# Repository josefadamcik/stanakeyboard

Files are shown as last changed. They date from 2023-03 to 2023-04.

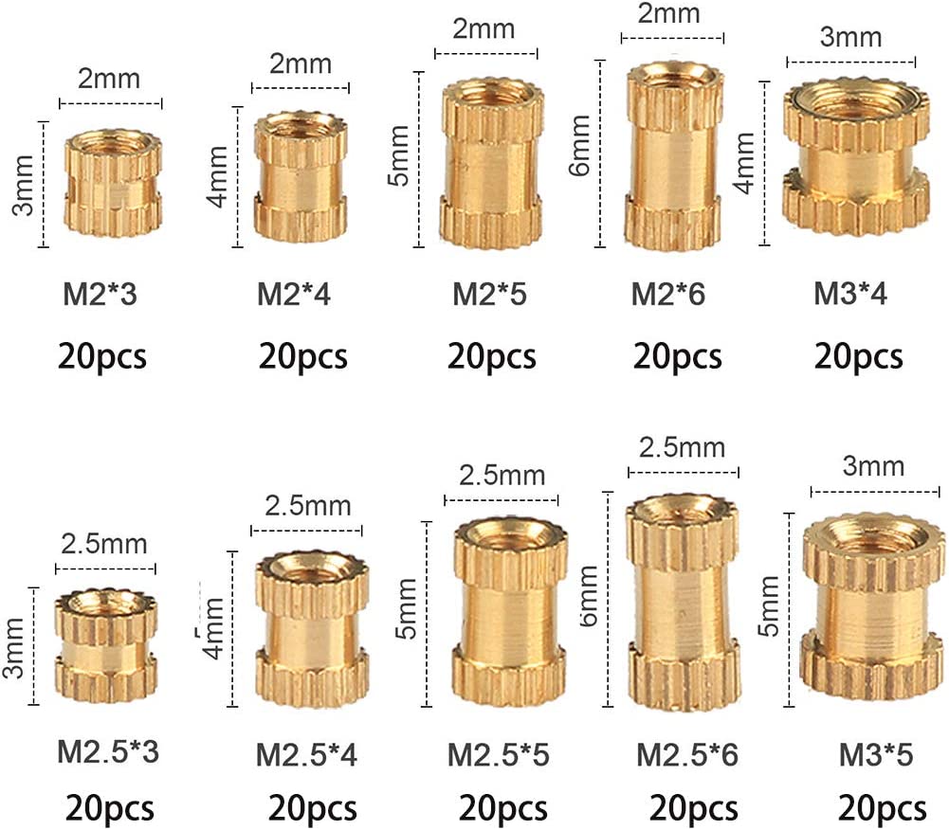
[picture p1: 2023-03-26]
doc/heat_inserts.jpg

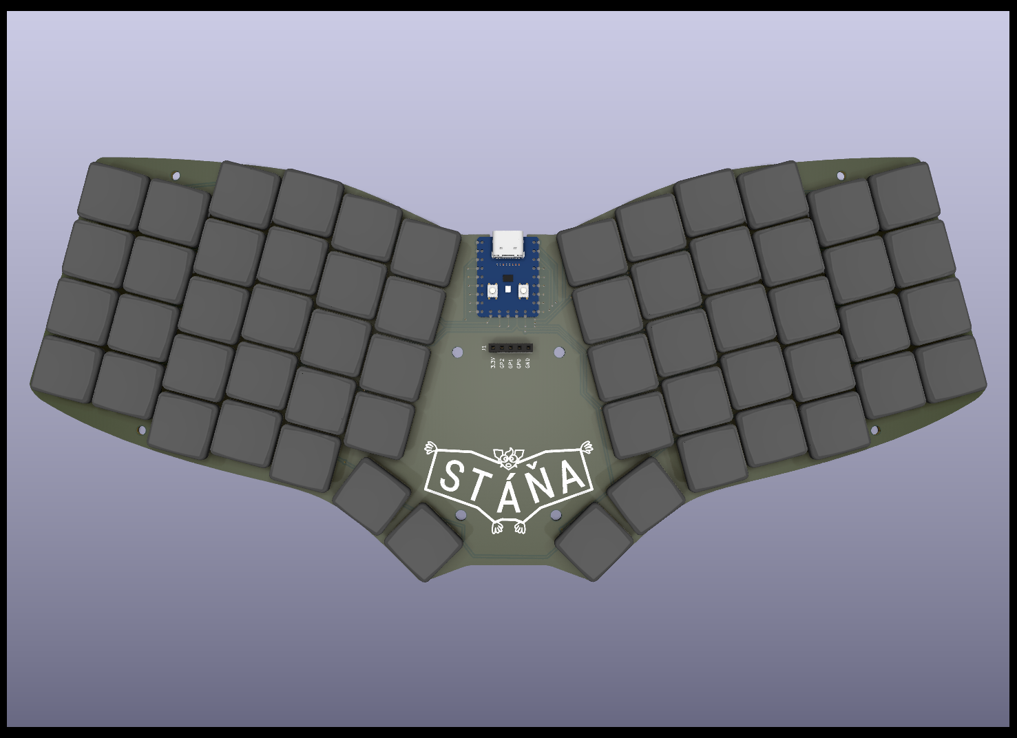
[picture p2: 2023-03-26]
doc/Stana_v0_1_render1.png

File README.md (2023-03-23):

# sofleunsplit

WIP DIY keyboard design.

* Sofle V2 layout
* But Kailh Chock with 18x17 spacing, socketed
* one board, one micro
* WaveShare RP2040
* no PCB plates -> case is going to be 3d printed/lasercut or something
* no RGB support

## Requirements

* Uses symbols/footprints from https://github.com/zzeneg/zzkeeb

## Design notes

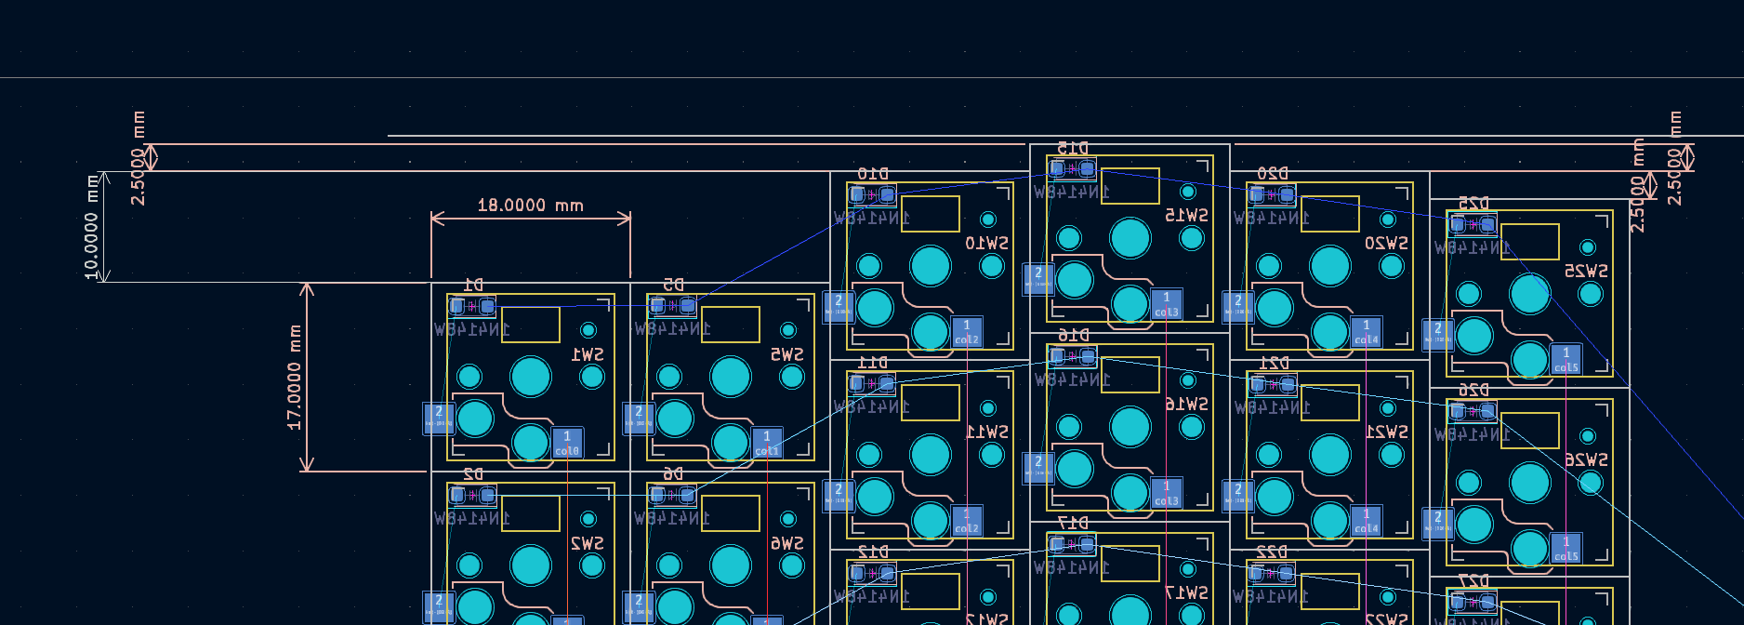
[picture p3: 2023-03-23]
doc/stagger.png

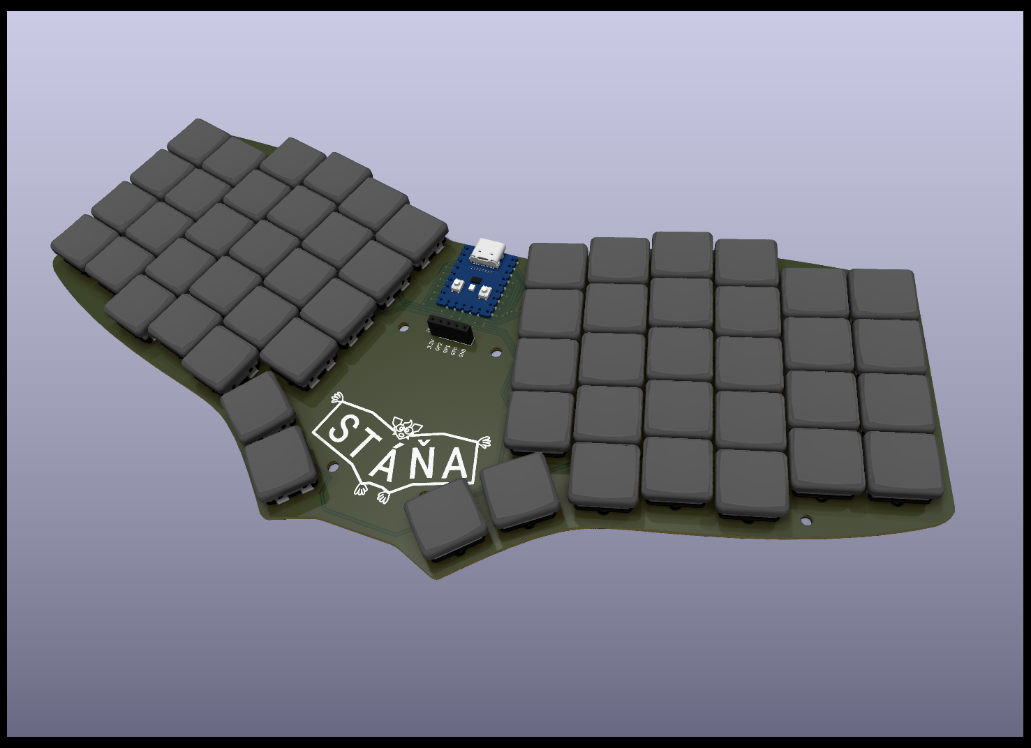
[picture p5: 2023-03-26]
doc/Stana_v0_1_render3.png

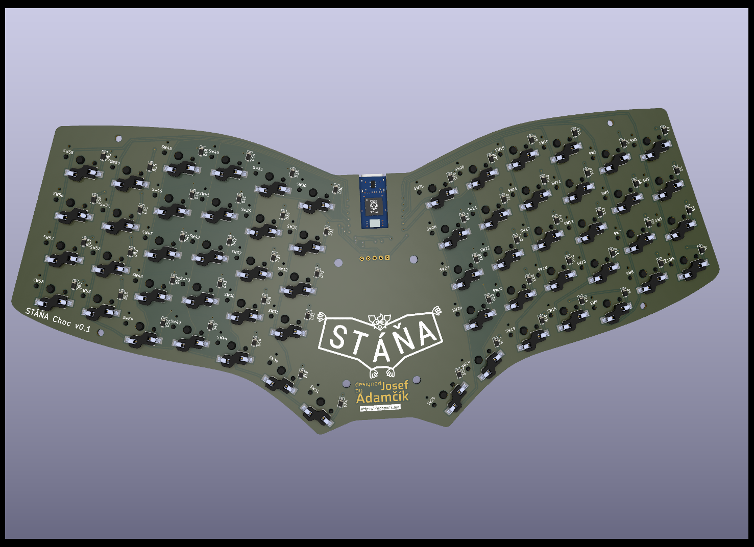
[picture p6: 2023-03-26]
doc/Stana_v0_1_render2.png

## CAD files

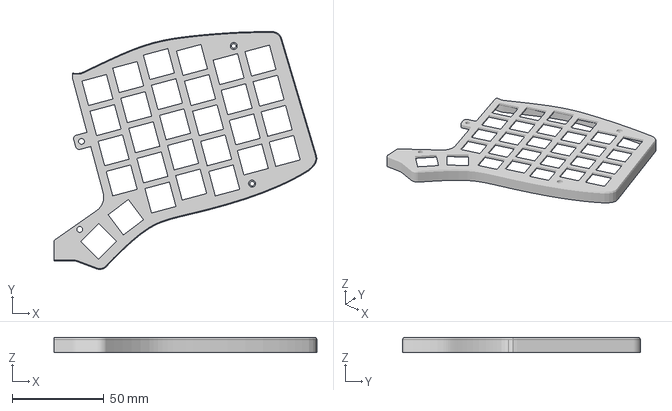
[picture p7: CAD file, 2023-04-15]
case/TopRightMirrorv4.3mf
143.4 x 129.7 x 8.00 mm

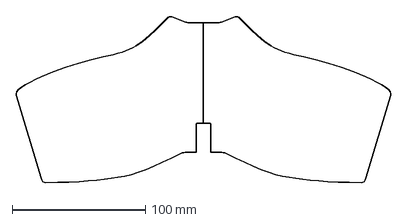
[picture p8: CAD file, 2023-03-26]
outline_design2.dxf
281.5 x 124.8 mm

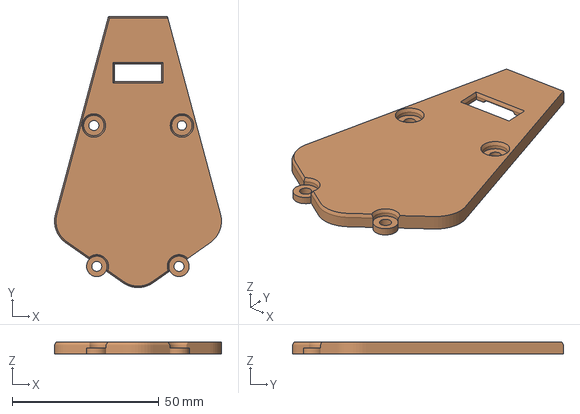
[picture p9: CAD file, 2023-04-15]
case/MiddleCover.3mf
56.9 x 92.4 x 4.00 mm

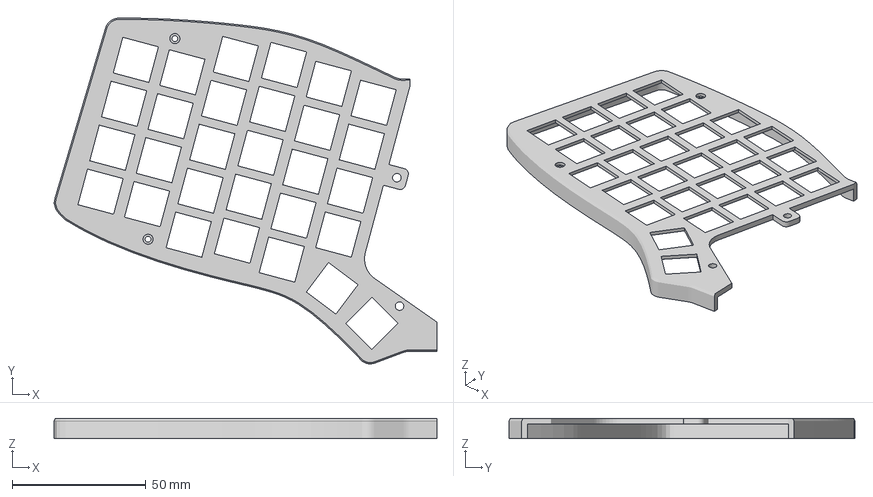
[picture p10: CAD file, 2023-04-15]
case/TopLeftv2.3mf
143.2 x 129.3 x 7.60 mm

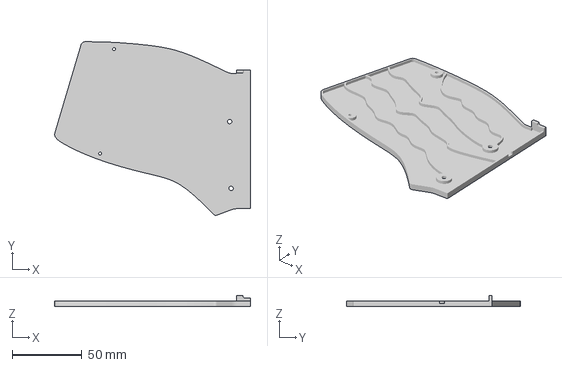
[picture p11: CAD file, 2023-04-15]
case/BottomLeft.3mf
140.8 x 124.7 x 7.80 mm

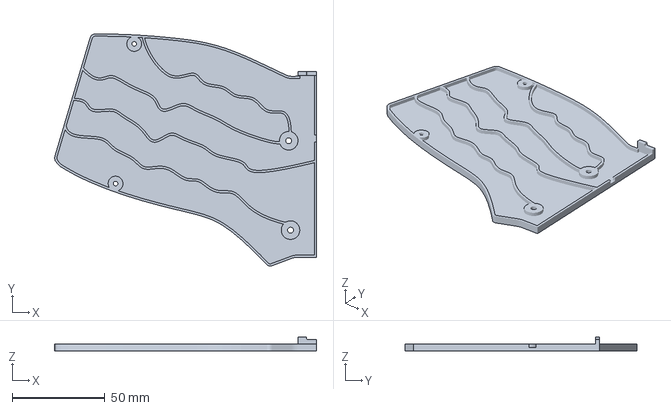
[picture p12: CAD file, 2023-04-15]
case/BottomLeftV2_compensate_for_shrinkx033_y037.3mf
141.2 x 125.1 x 7.80 mm

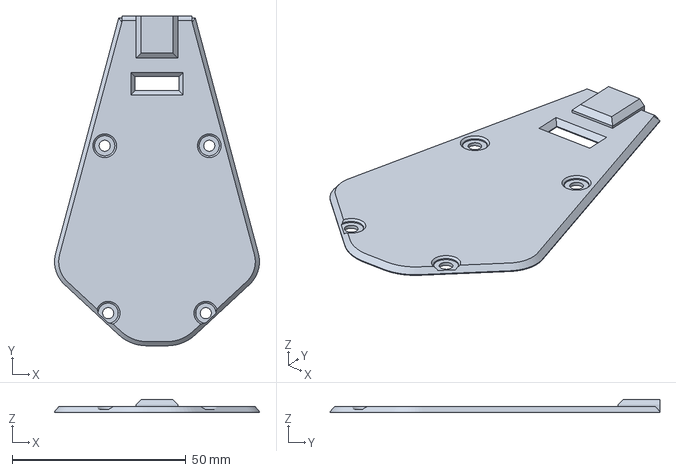
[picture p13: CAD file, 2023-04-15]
case/BottomLeftv3_compensate_for_shrinkx033_y037.3mf
59.0 x 94.9 x 3.60 mm

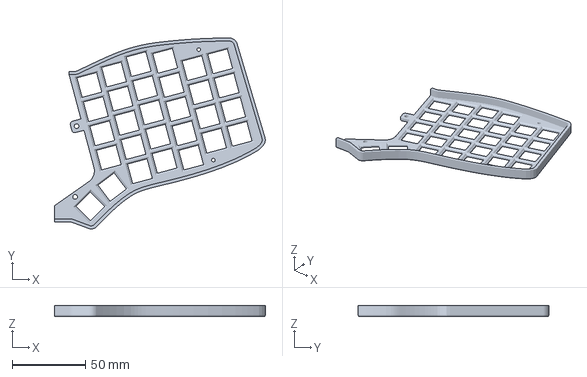
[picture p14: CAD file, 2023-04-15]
case/TopLeftv3_compensate_for_shrinkx033_y037.3mf
143.9 x 130.2 x 7.60 mm

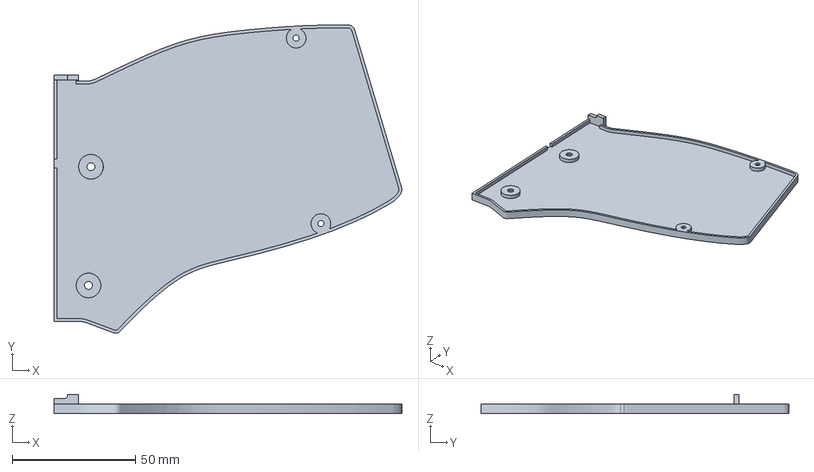
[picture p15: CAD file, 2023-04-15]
case/BottormRightMirrorv2_compensate_for_shrinkx033_y037.3mf
141.2 x 125.1 x 7.83 mm

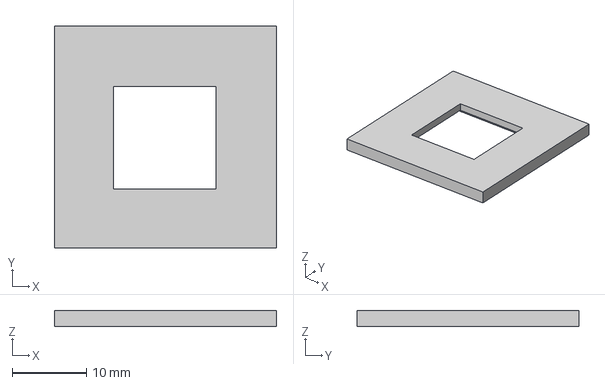
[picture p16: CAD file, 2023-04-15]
case/test plate switch cut 1.3mf
30.0 x 30.0 x 2.20 mm

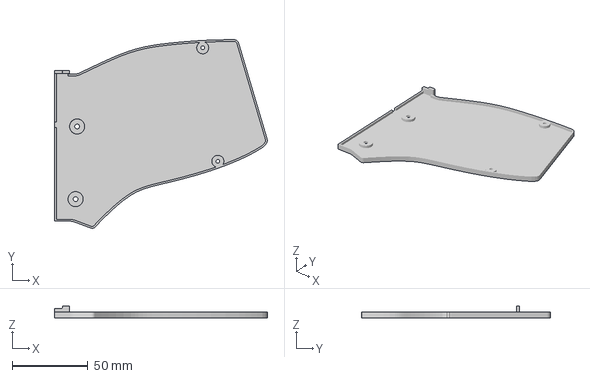
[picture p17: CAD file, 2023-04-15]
case/BottomRightMirrorv2.3mf
140.8 x 124.7 x 7.80 mm

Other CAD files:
case/TopLeftv4_compensate_for_shrinkx033_y037.3mf
case/BottomLeftv3.3mf
case/TopLeftv4.3mf
case/TopRightMirror.3mf
case/MiddleCover2_compensate_for_shrinkx033_y037.3mf
case/BottomRightMirror_compensate_for_shrinkx033_y037.3mf
case/BottomRightMirror.3mf
case/BottomLeft.stl
case/BottomLeftV2.3mf
case/BottomRightMirror.stl
case/MiddleCover2.3mf
case/MiddleCover2.stl
case/TopLeft.3mf
case/TopLeftv3.3mf
case/TopLeftv3.stl
case/TopRightMirror.stl
case/TopRightMirrorv4_compensate_for_shrinkx033_y037.3mf

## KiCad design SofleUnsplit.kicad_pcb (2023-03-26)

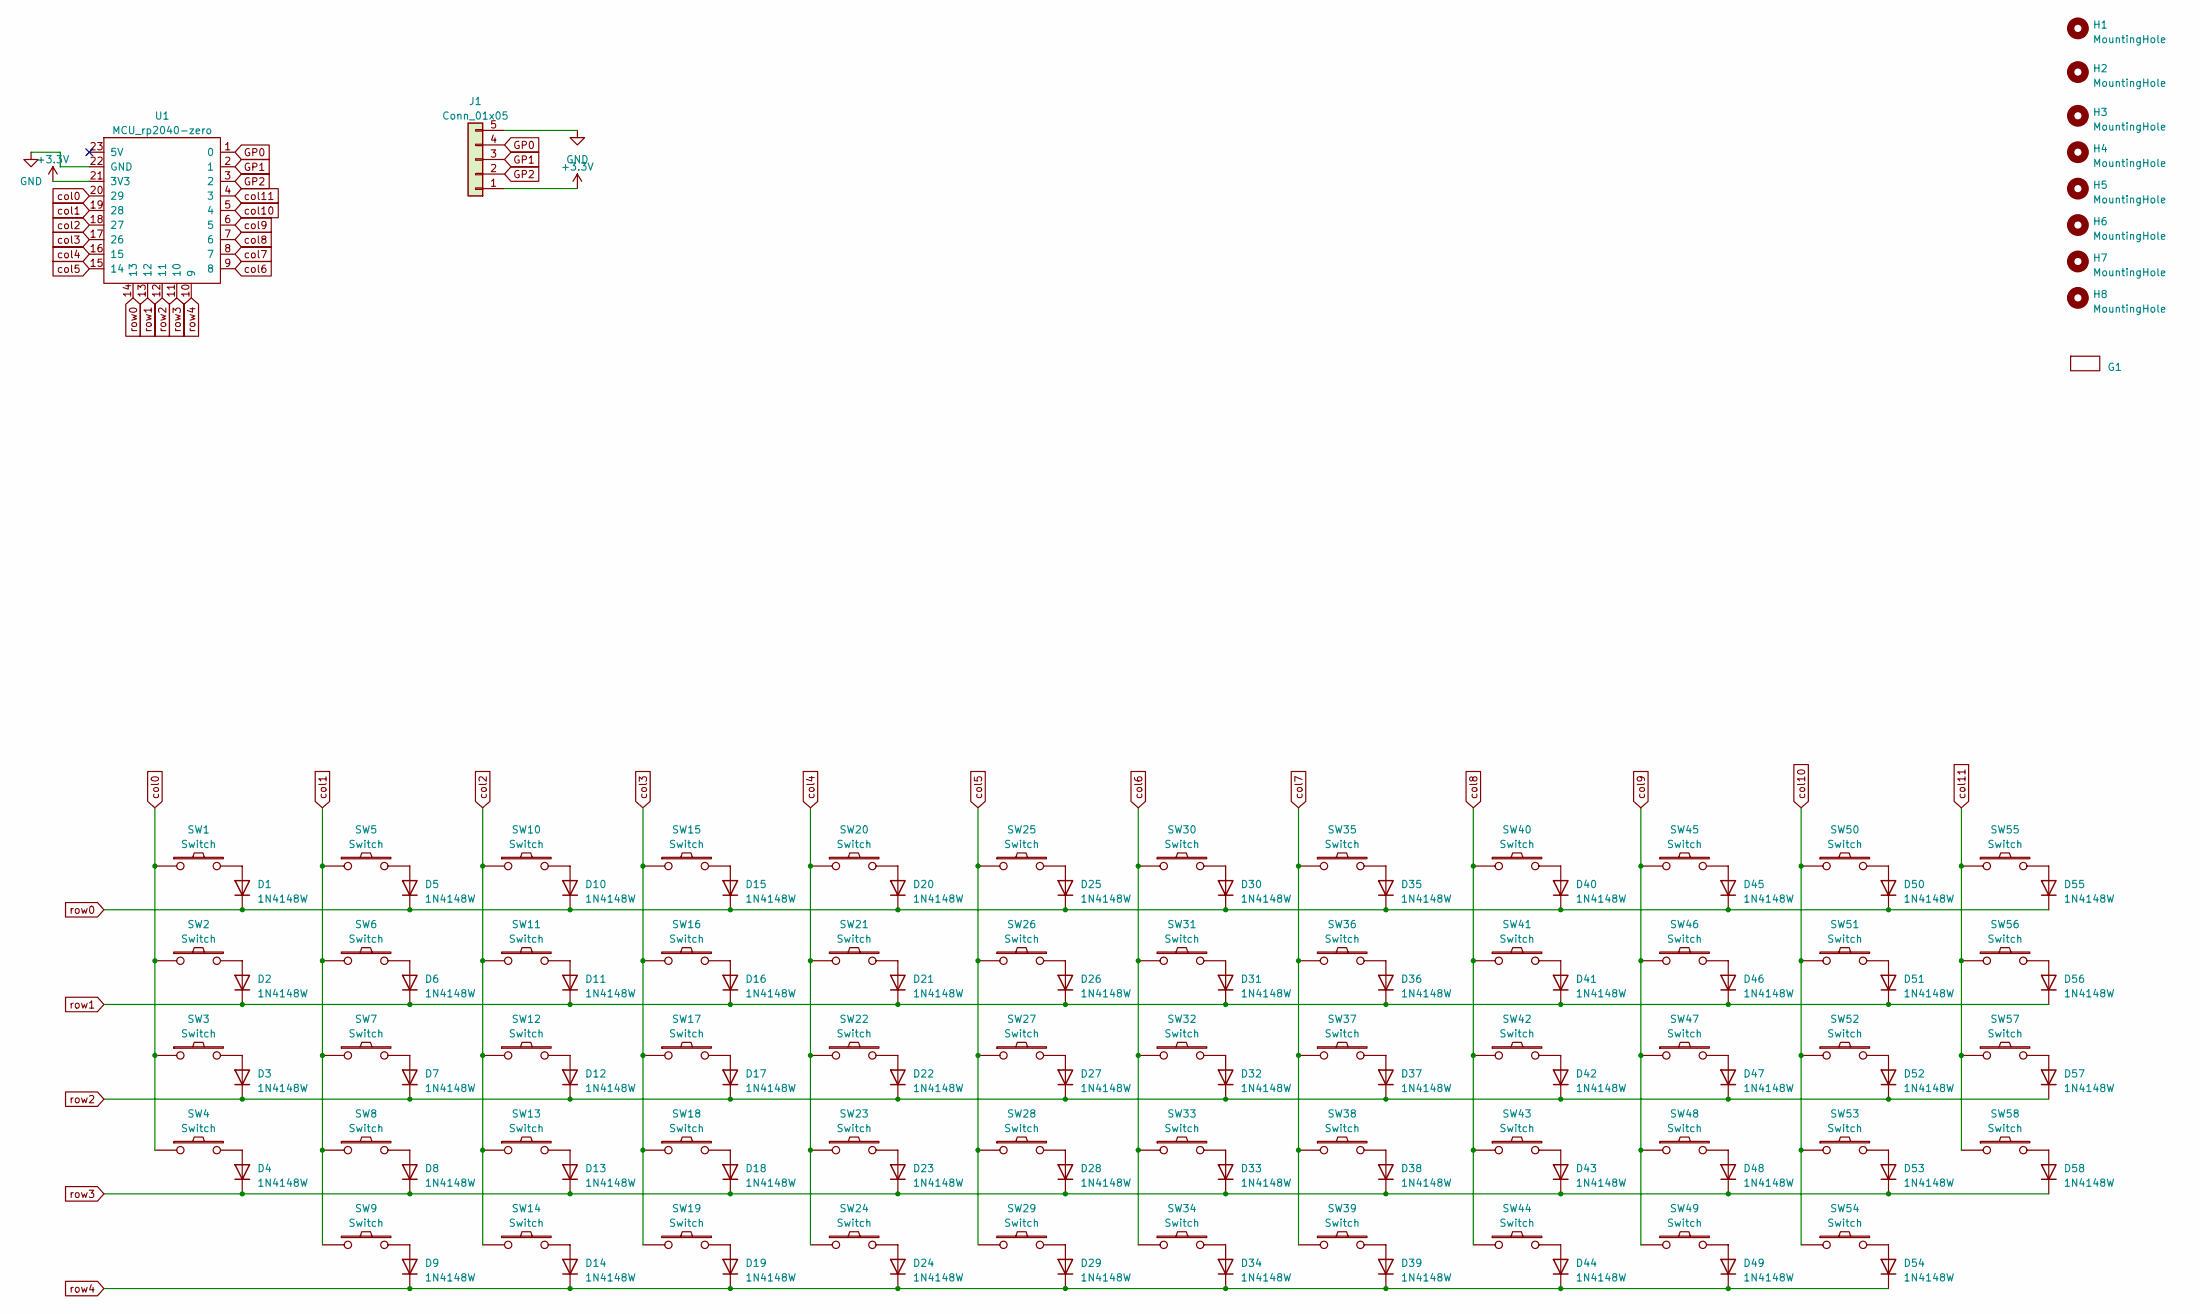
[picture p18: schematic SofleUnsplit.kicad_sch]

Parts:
D1, D2, D3, D4, D5, D6, D7, D8, D9, D10, D11, D12, D13, D14, D15, D16, D17, D18, D19, D20, D21, D22, D23, D24, D25, D26, D27, D28, D29, D30, D31, D32, D33, D34, D35, D36, D37, D38, D39, D40, D41, D42, D43, D44, D45, D46, D47, D48, D49, D50, D51, D52, D53, D54, D55, D56, D57, D58: 1N4148W; D_SOD-123F
G1: josef_adamcik_20mm_cu_mask
H1, H2, H3, H4: MountingHole; MountingHole_2.7mm_M2.5_DIN965
H5, H6, H7, H8: MountingHole; MountingHole_3.2mm_M3_DIN965
J1: Conn_01x05; PinSocket_1x05_P2.54mm_Vertical
SW1, SW2, SW3, SW4, SW5, SW6, SW7, SW8, SW9, SW10, SW11, SW12, SW13, SW14, SW15, SW16, SW17, SW18, SW19, SW20, SW21, SW22, SW23, SW24, SW25, SW26, SW27, SW28, SW29, SW30, SW31, SW32, SW33, SW34, SW35, SW36, SW37, SW38, SW39, SW40, SW41, SW42, SW43, SW44, SW45, SW46, SW47, SW48, SW49, SW50, SW51, SW52, SW53, SW54, SW55, SW56, SW57, SW58: Switch; Switch_ChocV1-hotswap
U1: MCU_rp2040-zero; MCU_rp2040-zero-smd

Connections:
+3.3V: J1.1, U1.21 (3V3)
GND: J1.5, U1.22 (GND)
GP0: J1.4, U1.1 (0)
GP1: J1.3, U1.2 (1)
GP2: J1.2, U1.3 (2)
unnamed: D1.2 (A), SW1.2
unnamed: D2.2 (A), SW2.2
unnamed: D3.2 (A), SW3.2
unnamed: D4.2 (A), SW4.2
unnamed: D5.2 (A), SW5.2
unnamed: D6.2 (A), SW6.2
unnamed: D7.2 (A), SW7.2
unnamed: D8.2 (A), SW8.2
unnamed: D9.2 (A), SW9.2
unnamed: D10.2 (A), SW10.2
unnamed: D11.2 (A), SW11.2
unnamed: D12.2 (A), SW12.2
unnamed: D13.2 (A), SW13.2
unnamed: D14.2 (A), SW14.2
unnamed: D15.2 (A), SW15.2
unnamed: D16.2 (A), SW16.2
unnamed: D17.2 (A), SW17.2
unnamed: D18.2 (A), SW18.2
unnamed: D19.2 (A), SW19.2
unnamed: D20.2 (A), SW20.2
unnamed: D21.2 (A), SW21.2
unnamed: D22.2 (A), SW22.2
unnamed: D23.2 (A), SW23.2
unnamed: D24.2 (A), SW24.2
unnamed: D25.2 (A), SW25.2
unnamed: D26.2 (A), SW26.2
unnamed: D27.2 (A), SW27.2
unnamed: D28.2 (A), SW28.2
unnamed: D29.2 (A), SW29.2
unnamed: D30.2 (A), SW30.2
unnamed: D31.2 (A), SW31.2
unnamed: D32.2 (A), SW32.2
unnamed: D33.2 (A), SW33.2
unnamed: D34.2 (A), SW34.2
unnamed: D35.2 (A), SW35.2
unnamed: D36.2 (A), SW36.2
unnamed: D37.2 (A), SW37.2
unnamed: D38.2 (A), SW38.2
unnamed: D39.2 (A), SW39.2
unnamed: D40.2 (A), SW40.2
unnamed: D41.2 (A), SW41.2
unnamed: D42.2 (A), SW42.2
unnamed: D43.2 (A), SW43.2
unnamed: D44.2 (A), SW44.2
unnamed: D45.2 (A), SW45.2
unnamed: D46.2 (A), SW46.2
unnamed: D47.2 (A), SW47.2
unnamed: D48.2 (A), SW48.2
unnamed: D49.2 (A), SW49.2
unnamed: D50.2 (A), SW50.2
unnamed: D51.2 (A), SW51.2
unnamed: D52.2 (A), SW52.2
unnamed: D53.2 (A), SW53.2
unnamed: D54.2 (A), SW54.2
unnamed: D55.2 (A), SW55.2
unnamed: D56.2 (A), SW56.2
unnamed: D57.2 (A), SW57.2
unnamed: D58.2 (A), SW58.2
col0: SW1.1, SW2.1, SW3.1, SW4.1, U1.20 (29)
col1: SW5.1, SW6.1, SW7.1, SW8.1, SW9.1, U1.19 (28)
col2: SW10.1, SW11.1, SW12.1, SW13.1, SW14.1, U1.18 (27)
col3: SW15.1, SW16.1, SW17.1, SW18.1, SW19.1, U1.17 (26)
col4: SW20.1, SW21.1, SW22.1, SW23.1, SW24.1, U1.16 (15)
col5: SW25.1, SW26.1, SW27.1, SW28.1, SW29.1, U1.15 (14)
col6: SW30.1, SW31.1, SW32.1, SW33.1, SW34.1, U1.9 (8)
col7: SW35.1, SW36.1, SW37.1, SW38.1, SW39.1, U1.8 (7)
col8: SW40.1, SW41.1, SW42.1, SW43.1, SW44.1, U1.7 (6)
col9: SW45.1, SW46.1, SW47.1, SW48.1, SW49.1, U1.6 (5)
col10: SW50.1, SW51.1, SW52.1, SW53.1, SW54.1, U1.5 (4)
col11: SW55.1, SW56.1, SW57.1, SW58.1, U1.4 (3)
row0: D1.1 (K), D5.1 (K), D10.1 (K), D15.1 (K), D20.1 (K), D25.1 (K), D30.1 (K), D35.1 (K), D40.1 (K), D45.1 (K), D50.1 (K), D55.1 (K), U1.14 (13)
row1: D2.1 (K), D6.1 (K), D11.1 (K), D16.1 (K), D21.1 (K), D26.1 (K), D31.1 (K), D36.1 (K), D41.1 (K), D46.1 (K), D51.1 (K), D56.1 (K), U1.13 (12)
row2: D3.1 (K), D7.1 (K), D12.1 (K), D17.1 (K), D22.1 (K), D27.1 (K), D32.1 (K), D37.1 (K), D42.1 (K), D47.1 (K), D52.1 (K), D57.1 (K), U1.12 (11)
row3: D4.1 (K), D8.1 (K), D13.1 (K), D18.1 (K), D23.1 (K), D28.1 (K), D33.1 (K), D38.1 (K), D43.1 (K), D48.1 (K), D53.1 (K), D58.1 (K), U1.11 (10)
row4: D9.1 (K), D14.1 (K), D19.1 (K), D24.1 (K), D29.1 (K), D34.1 (K), D39.1 (K), D44.1 (K), D49.1 (K), D54.1 (K), U1.10 (9)

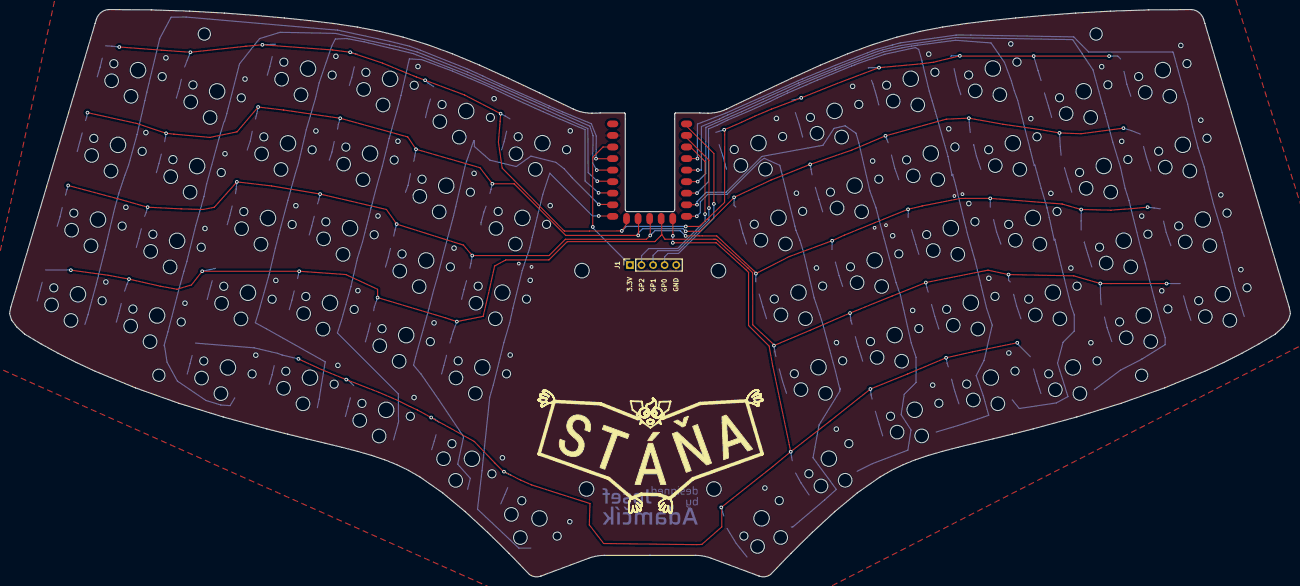
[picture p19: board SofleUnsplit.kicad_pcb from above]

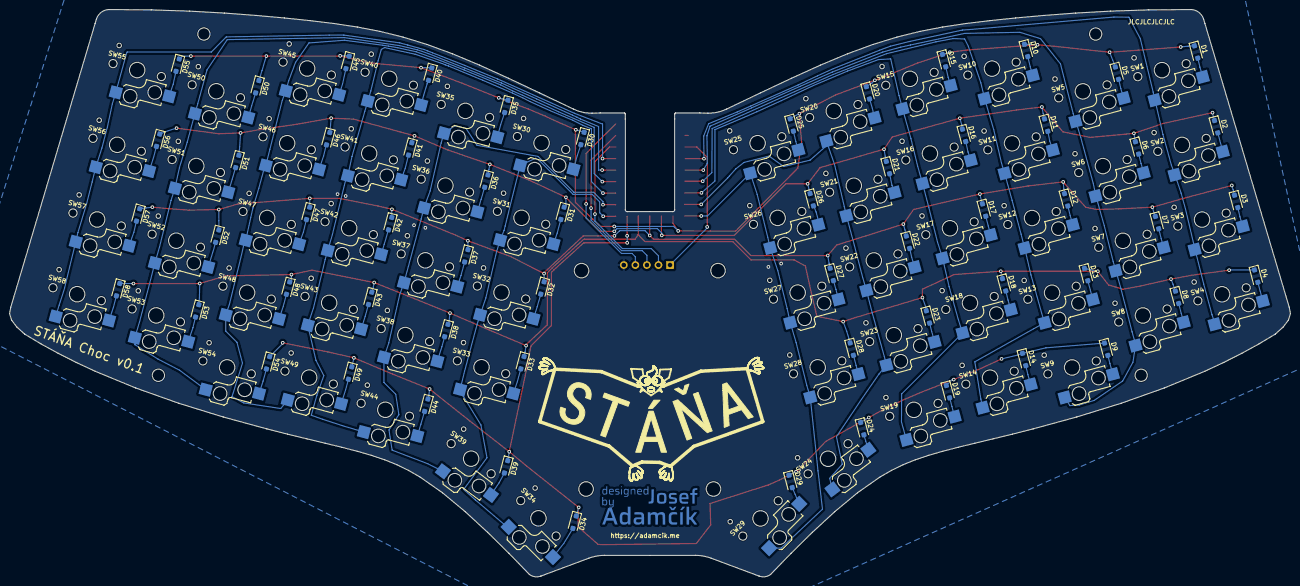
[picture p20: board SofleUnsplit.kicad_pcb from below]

Board: 2 copper layers, 281.5 x 124.7 mm, 127 parts (59 on the bottom side), 80 nets.

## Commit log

2023-03-23 Left half switches
    [SofleUnsplit.kicad_pcb, SofleUnsplit.kicad_sch]
2023-03-23 Both halves
    [SofleUnsplit.kicad_pcb]
2023-03-23 First version
    [SofleUnsplit.kicad_pcb]
2023-03-26 Improved shape in fusion360. Bit bigger and smooth curve.
    [SofleUnsplit.kicad_pcb, outline_design2.dxf]
2023-03-26 Place diodes differently
    [SofleUnsplit.kicad_pcb, SofleUnsplit.kicad_sch]
2023-03-26 Routing the right half WIP
    [SofleUnsplit.kicad_pcb]
2023-03-26 Right half routed
    [SofleUnsplit.kicad_pcb]
2023-03-26 Routing done
    [SofleUnsplit.kicad_pcb, SofleUnsplit.kicad_sch]
2023-03-26 Polishing, finishing
    [SofleUnsplit.kicad_pcb, SofleUnsplit.kicad_sch]
2023-03-26 First version, final, before last check.
    [SofleUnsplit-B_Cu.gbr, SofleUnsplit-B_Mask.gbr, SofleUnsplit-B_Paste.gbr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]
2023-03-26 Add placement for JLCPCB number
    [SofleUnsplit-B_Cu.gbr, SofleUnsplit-B_Mask.gbr, SofleUnsplit-B_Paste.gbr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]
2023-03-26 Minor fixes
    [SofleUnsplit-B_Cu.gbr, SofleUnsplit-B_Mask.gbr, SofleUnsplit-B_Paste.gbr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]
2023-03-27 Ues SOD-123 layout for dioedes (might be easier to solder by hand than SOD-123F even though I have SOD-123F diodes). Logo as footprint in copper.
    [SofleUnsplit-B_Cu.gbr, SofleUnsplit-B_Mask.gbr, SofleUnsplit-B_Paste.gbr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]
2023-03-27 Final changes
    [SofleUnsplit-B_Cu.gbr, SofleUnsplit-B_Mask.gbr, SofleUnsplit-B_Paste.gbr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]
2023-04-15 Iterating over case and logog
    [BottomLeft.3mf, BottomLeft.stl, BottomLeftV2.3mf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]
